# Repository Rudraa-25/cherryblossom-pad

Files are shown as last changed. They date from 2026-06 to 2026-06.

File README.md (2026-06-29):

# cherryblossom pad

this is my custom 12 key macropad project for the hack club hackpad. it use a seeed xiao rp2040 and got 12 switch and a small oled display. i design the case in cad and the pcb in kicad. also when [...]

here is some photos of my desgin:

**my 3d cad model:**
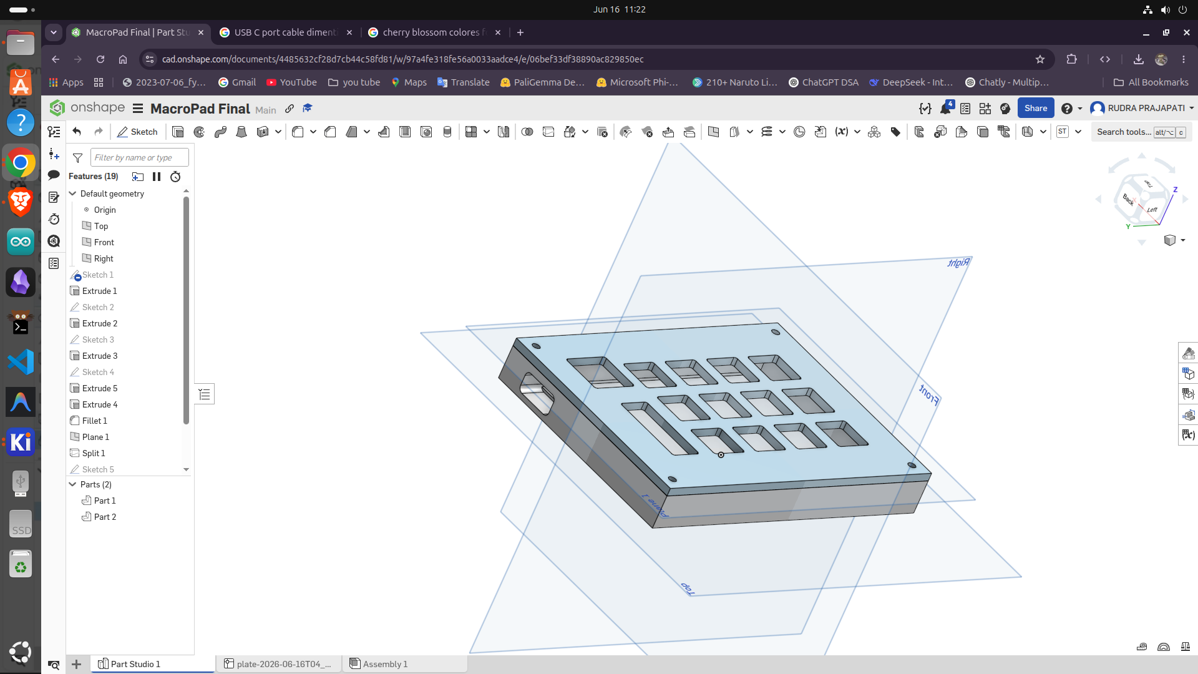
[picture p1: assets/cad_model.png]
CAD Model


**my pcb layout:**
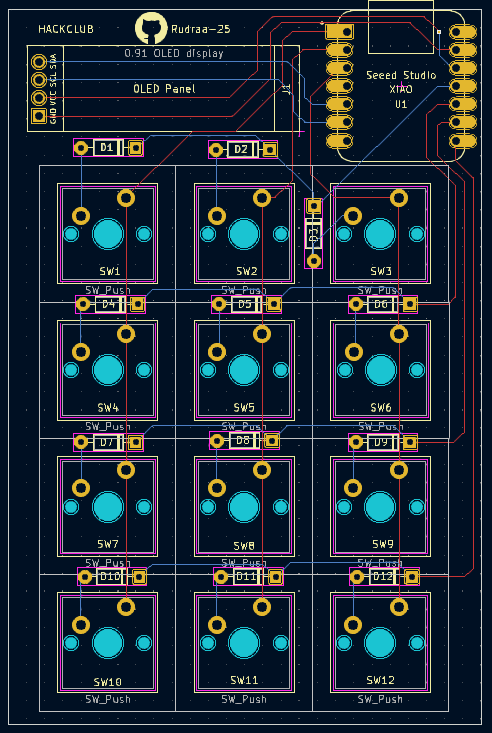
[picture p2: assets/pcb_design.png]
PCB Design


**the schematic:**
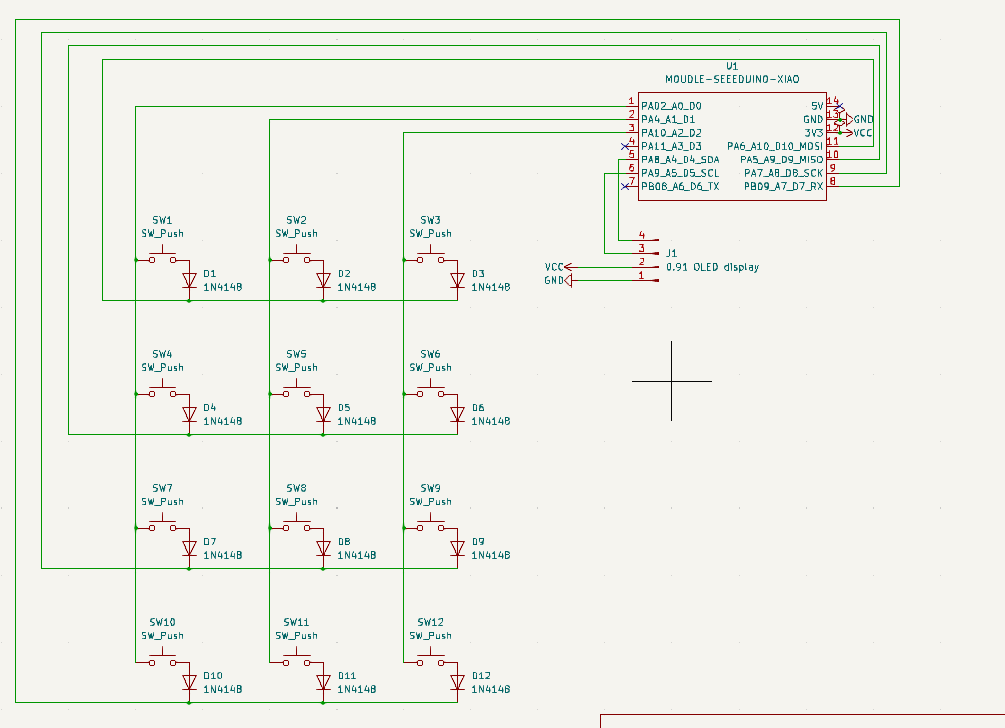
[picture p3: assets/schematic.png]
Schematic


### parts u need to build this
* 1x seeed studio xiao rp2040
* 1x 0.91 oled display
* 12x mx switches 
* 12x 1n4148 diodes
* my custom pcb (in the production folder)
* my 3d printed case (also in production folder)

check out `BOOM.csv` for the full bill of materials with pricing!

### firmwere setup
i am using KMK firmwere so its super simple. u dont need to compile any uf2 file yourself.
1. download the official circuitpython uf2 for the xiao rp2040 and drag it to the board.
2. download KMK firmwere and copy the `kmk` folder to the board
3. copy my `main.py` from the firmware folder to the board.
thats it it should work now!

### credits
- made with help of github copilot to generate the BOOM.csv bill of materials

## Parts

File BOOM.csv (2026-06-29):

Part Name | Quantity | Unit Cost (USD) | Total Cost (USD) | Supplier | Notes
Seeed Studio XIAO RP2040 | 1 | 8.50 | 8.50 | Seeed Studio | Microcontroller
0.91 OLED Display (128x32) | 1 | 3.50 | 3.50 | Amazon/Aliexpress | I2C Display
MX Mechanical Switches | 12 | 0.50 | 6.00 | Aliexpress/Banggood | Standard clones OK
1N4148 Diodes | 12 | 0.05 | 0.60 | Any electronics store | Standard SMD or through-hole
Custom PCB (Jlcpcb/Seeedstudio) | 1 | 2.00 | 2.00 | JLC PCB | 10 pieces typical order
3D Printed Case (Resin/FDM) | 1 | 2.00 | 2.00 | Local 3D printer | PLA filament ~50g
USB-C Cable | 1 | 1.00 | 1.00 | Generic | For programming
Miscellaneous (solder wire/flux/etc) | 1 | 1.00 | 1.00 | Available | Already have
TOTAL |  |  | 25.60 | TARGET | $24.60 - Under budget! 🎉

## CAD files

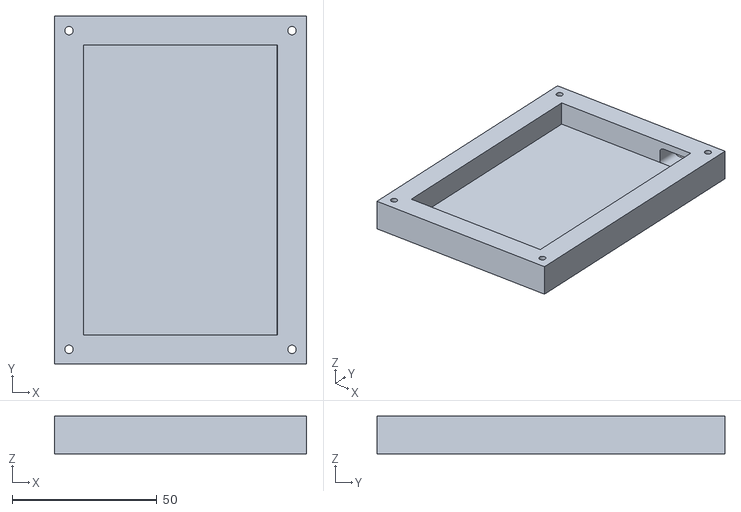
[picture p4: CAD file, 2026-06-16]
production/mainbody.stl
87.0 x 120.0 x 13.0

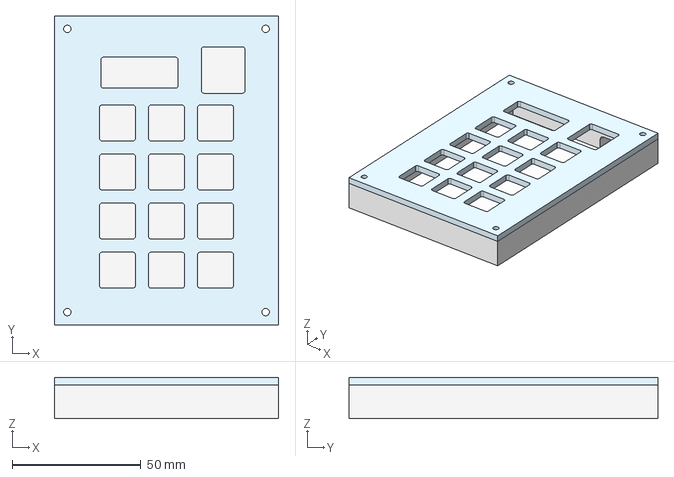
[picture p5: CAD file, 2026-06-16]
cad/macropad_v3.step
87.0 x 120.0 x 16.0 mm

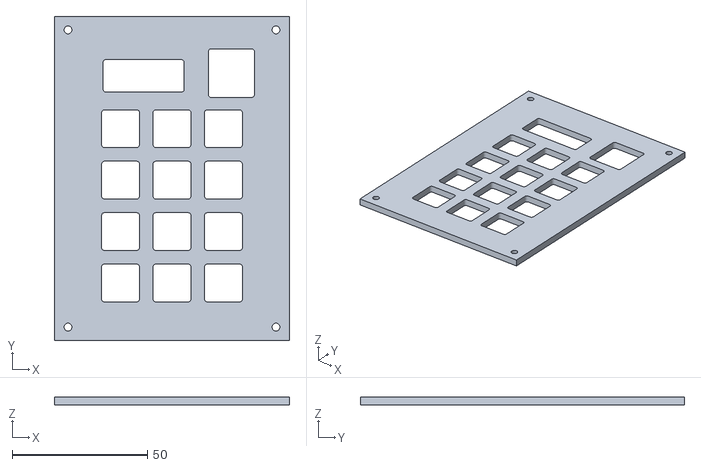
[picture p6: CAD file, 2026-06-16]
production/top_cover.stl
87.0 x 120.0 x 3.00

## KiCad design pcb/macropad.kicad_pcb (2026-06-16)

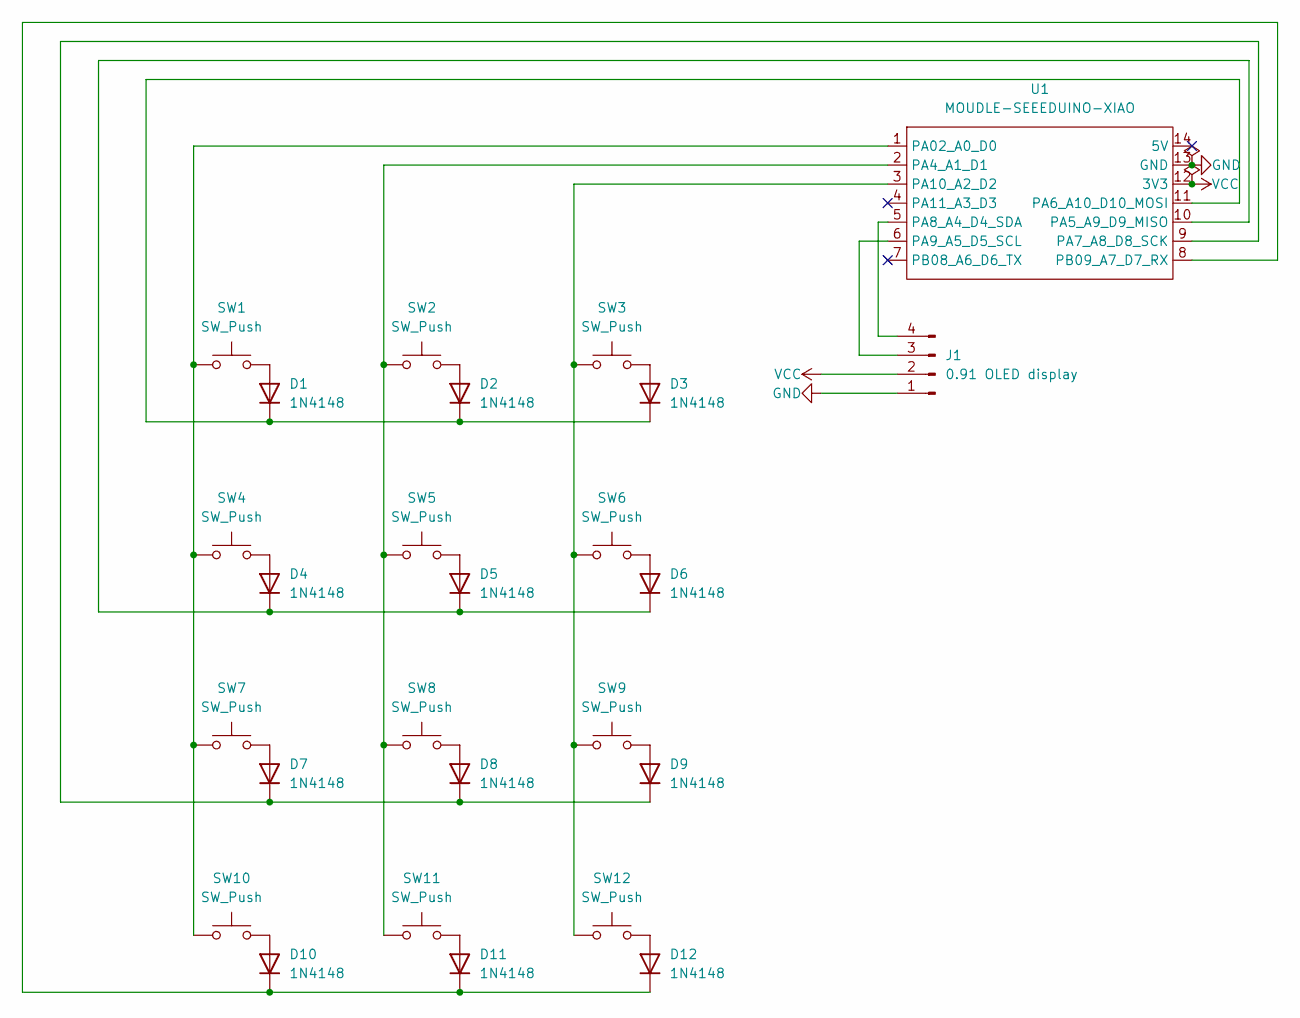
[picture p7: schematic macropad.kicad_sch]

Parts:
D1, D2, D3, D4, D5, D6, D7, D8, D9, D10, D11, D12: 1N4148; D_DO-35_SOD27_P7.62mm_Horizontal
J1: 0.91 OLED display; SSD1306-0.91-OLED-4pin-128x32
SW1, SW2, SW3, SW4, SW5, SW6, SW7, SW8, SW9, SW10, SW11, SW12: SW_Push; SW_Cherry_MX_1.00u_PCB
U1: MOUDLE-SEEEDUINO-XIAO; XIAO-Generic-Hybrid-14P-2.54-21X17.8MM

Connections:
GND: J1.1, U1.13 (GND)
unnamed: D1.2 (A), SW1.2
unnamed: D1.1 (K), D2.1 (K), D3.1 (K), U1.11 (PA6_A10_D10_MOSI)
unnamed: D2.2 (A), SW2.2
unnamed: D3.2 (A), SW3.2
unnamed: D4.2 (A), SW4.2
unnamed: D4.1 (K), D5.1 (K), D6.1 (K), U1.10 (PA5_A9_D9_MISO)
unnamed: D5.2 (A), SW5.2
unnamed: D6.2 (A), SW6.2
unnamed: D7.2 (A), SW7.2
unnamed: D7.1 (K), D8.1 (K), D9.1 (K), U1.9 (PA7_A8_D8_SCK)
unnamed: D8.2 (A), SW8.2
unnamed: D9.2 (A), SW9.2
unnamed: D10.2 (A), SW10.2
unnamed: D10.1 (K), D11.1 (K), D12.1 (K), U1.8 (PB09_A7_D7_RX)
unnamed: D11.2 (A), SW11.2
unnamed: D12.2 (A), SW12.2
unnamed: J1.3, U1.6 (PA9_A5_D5_SCL)
unnamed: J1.4, U1.5 (PA8_A4_D4_SDA)
unnamed: SW1.1, SW4.1, SW7.1, SW10.1, U1.1 (PA02_A0_D0)
unnamed: SW2.1, SW5.1, SW8.1, SW11.1, U1.2 (PA4_A1_D1)
unnamed: SW3.1, SW6.1, SW9.1, SW12.1, U1.3 (PA10_A2_D2)
VCC: J1.2, U1.12 (3V3)

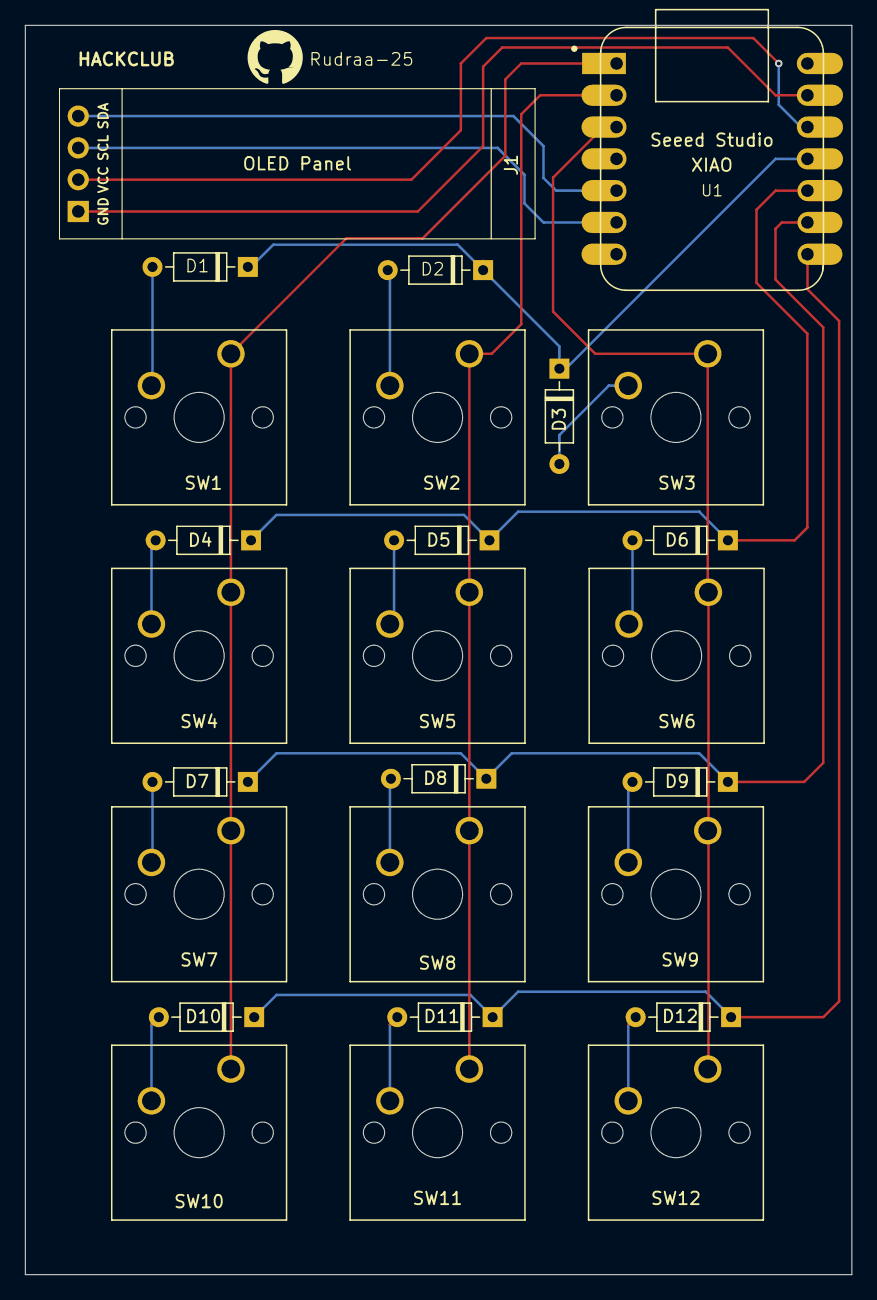
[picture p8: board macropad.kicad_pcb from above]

Board: 2 copper layers, 66.0 x 99.8 mm, 26 parts (0 on the bottom side), 23 nets.

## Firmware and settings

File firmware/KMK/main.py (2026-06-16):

import board
import busio

from kmk.kmk_keyboard import KMKKeyboard
from kmk.keys import KC
from kmk.scanners import DiodeOrientation
from kmk.extensions.display import Display, TextEntry, ImageEntry
from kmk.extensions.display.ssd1306 import SSD1306

keyboard = KMKKeyboard()

# Matrix setup
# Rows: D0, D1, D2, D3
keyboard.col_pins = (board.D10, board.D9, board.D8)
keyboard.row_pins = (board.D0, board.D1, board.D2, board.D3)
keyboard.diode_orientation = DiodeOrientation.ROW2COL

# I2C setup for OLED (SDA=D4, SCL=D5)
i2c = busio.I2C(board.D5, board.D4)

# Display setup (0.91" OLED is typically 128x32)
display_driver = SSD1306(
    i2c=i2c,
    device_address=0x3C, # Default I2C address for SSD1306
    width=128,
    height=32
)

display = Display(
    display=display_driver,
    entries=[
        TextEntry(text='cherryblossom pad', x=0, y=0, y_anchor='B'),
        TextEntry(text='Layer: BASE', x=0, y=10, y_anchor='B'),
    ],
    width=128,
    height=32,
    dim_time=10,
    dim_target=0.2,
    off_time=1200,
    brightness=1,
)

keyboard.extensions.append(display)

# Keymap configuration
keyboard.keymap = [
    [
        KC.N1, KC.N2, KC.N3,
        KC.N4, KC.N5, KC.N6,
        KC.N7, KC.N8, KC.N9,
        KC.N0, KC.A,  KC.B
    ]
]

if __name__ == '__main__':
    keyboard.go()

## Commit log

2026-06-12 Initial commit of KiCad Macropad 2.0 project and Gerbers
    [macropad.kicad_pcb, macropad.kicad_sch]
2026-06-16 Initial commit of cherryblossom pad for Hackpad
    [macropad.kicad_pcb, macropad.kicad_sch, macropad_v3.step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]
2026-06-29 Add bill of materials (BOOM) for macro pad project under $25
    [BOOM.csv]
